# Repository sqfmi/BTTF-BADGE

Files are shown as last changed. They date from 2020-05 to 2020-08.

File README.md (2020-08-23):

# BTTF BADGE
BTTF

Order PCBs from OSHPARK (Choose After Dark PCBs for Best Results): https://oshpark.com/projects/hdZOu9qd

## Bill of Materials
| Component | Quantity | Link |
|---|---|---|
| LED 0603 | 24 | |
| S8050 SOT-23 | 8 | |
| 10K Resistor Array 4x0603 | 2 |https://www.digikey.com/product-detail/en/panasonic-electronic-components/EXB-38V103JV/Y9103CT-ND/256604 |
| 74HC4017 SOIC-16 | 1 |https://www.digikey.com/product-detail/en/texas-instruments/CD74HC4017M96/296-12808-1-ND/475934 |
| 74LVC1G14 SOT-353 | 1 |https://www.digikey.com/product-detail/en/diodes-incorporated/74LVC1G14SE-7/74LVC1G14SE-7CT-ND/3829423 |
| 30K Trimmer Pot | 1 |https://www.digikey.com/product-detail/en/bourns-inc/TC33X-2-303E/TC33X-2-303ECT-ND/3437933 |
| 10uF 0805 | 1 | |
| CR2032 Battery Holder | 1 | https://www.digikey.com/product-detail/en/keystone-electronics/3034/36-3034-ND/4499289 |
| SAO Connector | 1 | |

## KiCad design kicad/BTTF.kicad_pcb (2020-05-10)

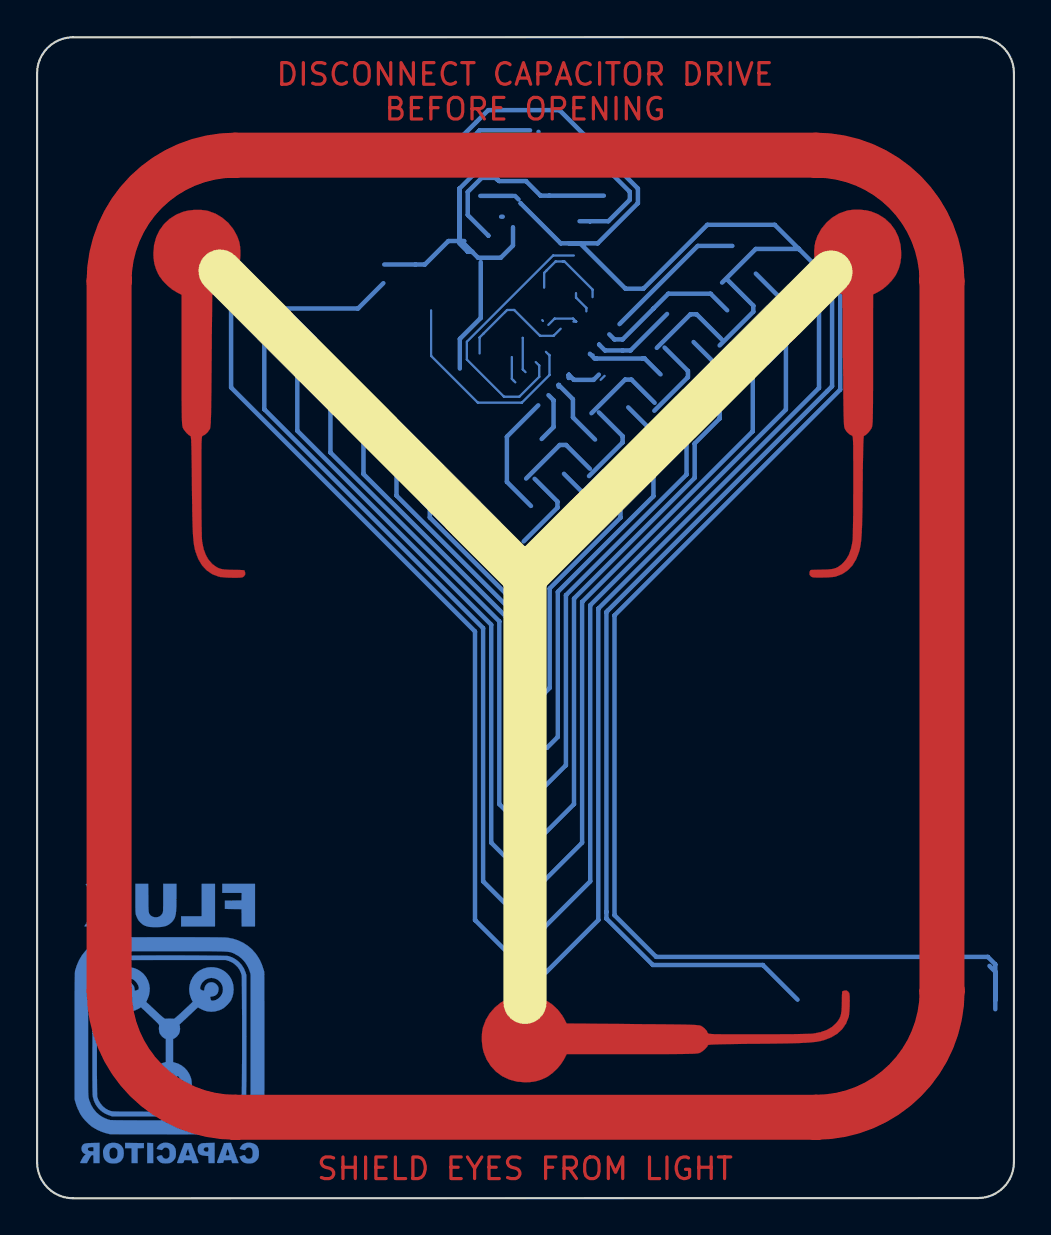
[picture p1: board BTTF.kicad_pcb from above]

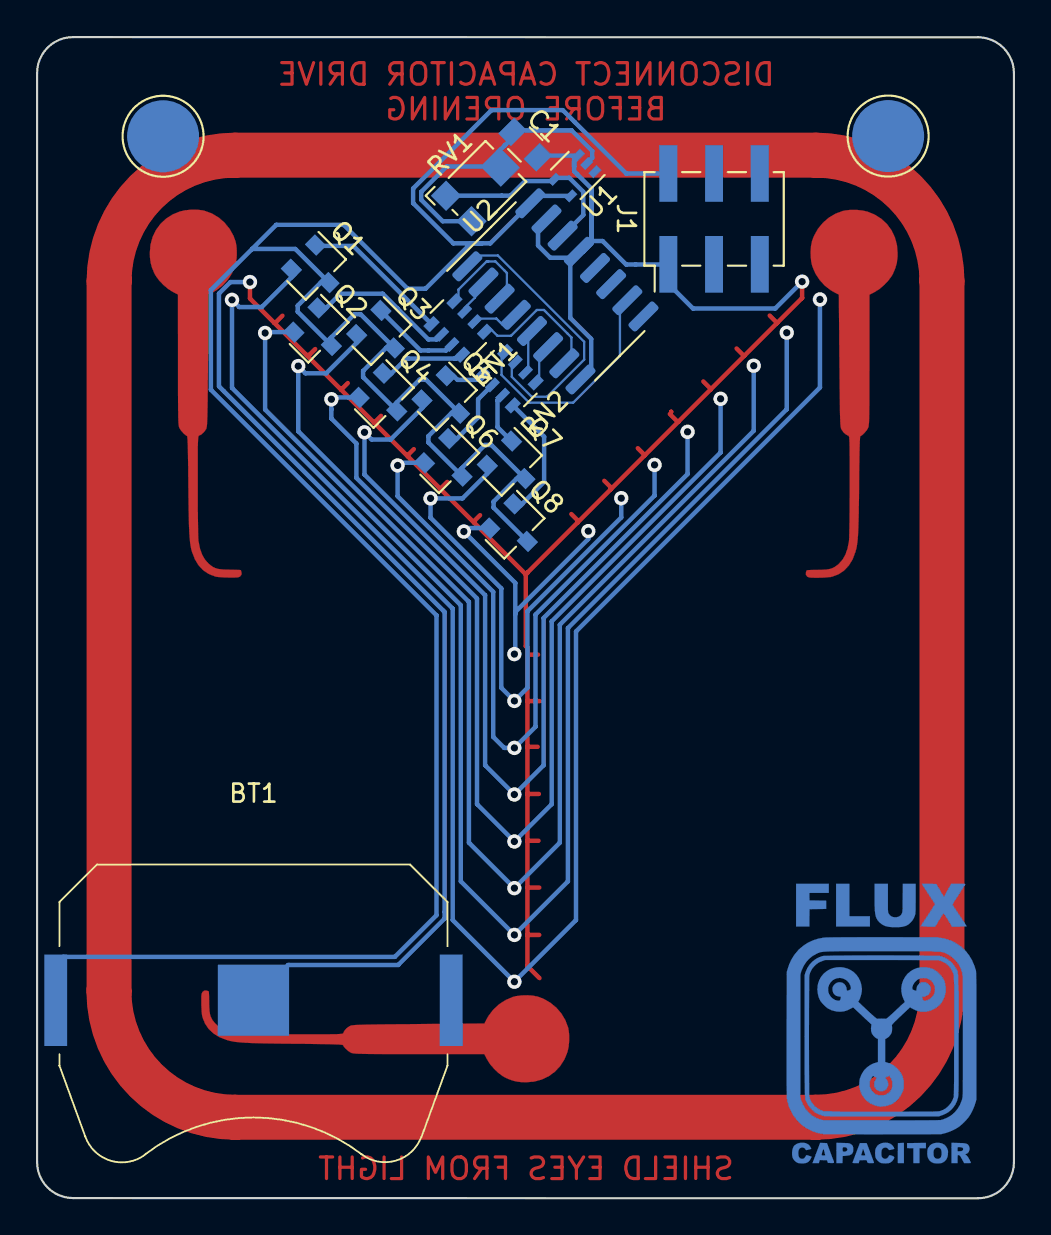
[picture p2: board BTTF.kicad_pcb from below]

Board: 2 copper layers, 54.3 x 64.5 mm, 40 parts (16 on the bottom side), 28 nets.

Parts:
BT1: CR2032; Keystone_3034_1x20mm-CoinCell
C1: 10uF; C_0805
D1A1, D1B1, D1C1, D2A1, D2B1, D2C1, D3A1, D3B1, D3C1, D4A1, D4B1, D4C1, D5A1, D5B1, D5C1, D6A1, D6B1, D6C1, D7A1, D7B1, D7C1, D8A1, D8B1, D8C1: LED; R_0603
J1: SAO; Pin_Header_Straight_2x03_Pitch2.54mm_SMD
Q1, Q2, Q3, Q4, Q5, Q6, Q7, Q8: S8050; SOT-23
RN1, RN2: 10K; R_Array_Convex_4x0603
RV1: 30K; Potentiometer_Bourns_TC33X_Vertical
U1: 74LVC1G14; SOT-353_SC-70-5
U2: 74HC4017; SOIC-16_3.9x9.9mm_P1.27mm

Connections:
GND: BT1.2, C1.2, D1A1.1, D1B1.1, D1C1.1, D2A1.1, D2B1.1, D2C1.1, D3A1.1, D3B1.1, D3C1.1, D4A1.1, D4B1.1, D4C1.1, D5A1.1, D5B1.1, D5C1.1, D6A1.1, D6B1.1, D6C1.1, D7A1.1, D7B1.1, D7C1.1, D8A1.1, D8B1.1, D8C1.1, J1.1, U1.3, U2.8, U2.13, U2.15
LED1: Q1.1, RN1.5
LED2: Q2.1, RN1.6
LED3: Q3.1, RN1.7
LED4: Q4.1, RN1.8
LED5: Q5.1, RN2.5
LED6: Q6.1, RN2.6
LED7: Q7.1, RN2.7
LED8: Q8.1, RN2.8
unnamed: C1.1, RV1.2, RV1.3, U1.2
unnamed: D1A1.2, D1B1.2, D1C1.2, Q1.2
unnamed: D2A1.2, D2B1.2, D2C1.2, Q2.2
unnamed: D3A1.2, D3B1.2, D3C1.2, Q3.2
unnamed: D4A1.2, D4B1.2, D4C1.2, Q4.2
unnamed: D5A1.2, D5B1.2, D5C1.2, Q5.2
unnamed: D6A1.2, D6B1.2, D6C1.2, Q6.2
unnamed: D7A1.2, D7B1.2, D7C1.2, Q7.2
unnamed: D8A1.2, D8B1.2, D8C1.2, Q8.2
unnamed: RN1.1, U2.7
unnamed: RN1.2, U2.4
unnamed: RN1.3, U2.2
unnamed: RN1.4, U2.3
unnamed: RN2.1, U2.6
unnamed: RN2.2, U2.5
unnamed: RN2.3, U2.1
unnamed: RN2.4, U2.10
unnamed: RV1.1, U1.4, U2.14
VCC: BT1.1, J1.2, Q1.3, Q2.3, Q3.3, Q4.3, Q5.3, Q6.3, Q7.3, Q8.3, U1.5, U2.16

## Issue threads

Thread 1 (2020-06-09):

Question: how does the clock circuit work.

MichMich, 2020-06-09:
First let me start by making a compliment about the beautiful pcb. I love it! And excuse me for "abusing" the GitHub issues for this question.

I ordered the PCB as a fathers day present for my dad. I was studying the circuit to see how it works, and fail to grasp how the clock signal is generated:
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

I'm a beginner when it comes to analog circuits but very eager to learn. So hopefully you can shine a light on the black magic. :)

Thanks in advance!

sqfmi, 2020-06-09:
Thanks @MichMich! That is very thoughtful, I'm sure your dad will love the gift 😄 Check out https://www.allaboutcircuits.com/technical-articles/exactly-how-schmitt-trigger-oscillators-work/ , it's a great article that explains how the oscillator works and how the frequency is calculated

MichMich, 2020-06-09:
Ah! That was extremely helpful! Thanks for the link. And once again thanks for the nice design!

Closed 2020-06-09.

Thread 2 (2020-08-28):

Dim LEDS

MichMich, 2020-08-28:
I finally received all parts I need for my first BTTF badge. It looks really cool, but it seems my LEDs are way to dim. When I feed 3V directly to the LEDS they have the desired brightness, but via the circuitry it seems they don't get the necessary voltage.

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

Above example is powered by a new CR2032.

My guess is I used the wrong transistors. Any other things I should or could check?

Thanks again for your help! :)

sqfmi, 2020-08-28:
Looks great! The brightness of the LEDs really depends on the forward voltage of the LEDs you chose, and the amount of current your battery is able to supply. For reference, we used these LEDs: https://www.digikey.com/product-detail/en/w-rth-elektronik/150060YS75000/732-4981-1-ND and a Panasonic CR2032.

MichMich, 2020-08-28:
Well, the thing is. It's the same when powered with my bench supply. If I power the LEDs directly with 3V, they have the correct brightness. But via the circuitry it seems they don't get the necessary voltage and are dim. I measured the voltage after the transistor and it looks like that voltage is below the supply voltage. Maybe the transistors don't get fully saturated?

sqfmi, 2020-08-28:
It really depends on what the forward voltage of the LEDs you chose, e.g. red/yellow/green LEDs are typically ~2V, while white/blue are typically ~3V. The transistors themselves have a slight voltage drop as well even when fully saturated, so I think if you want to have the LEDs to be brighter, you can try swapping out the resistor array, or different NPNs with a lower voltage drop (here's some reference material to help choose the right values https://www.nutsvolts.com/magazine/article/may2015_Secura). Hope this help!

robtheriot, 2024-08-14:
Are there instructions on how to put this all together? or should I have known better? parts are inbound....
